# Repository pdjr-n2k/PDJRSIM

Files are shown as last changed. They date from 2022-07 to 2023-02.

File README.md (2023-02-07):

# PDJRSIM - NMEA 2000 switch input module

This project provides a
[hardware design](./hardware/)
and associated
[firmware](./firmware)
for a 16-channel NMEA 2000 switch input module.

There is also a
[User Manual](./docs)
for a device constructed from these components.

**PDJRSIM** is a specialisation of
[NOP100](https://github.com/preeve9534/NOP100).

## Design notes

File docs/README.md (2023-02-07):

# PDJRSIM - NMEA 2000 switch input module

**PDJRSIM** is a 16-channel NMEA 2000 switch input module.

The module presents on the NMEA bus as a switch bank device with
Class Code 30 (Electrical Distribution) and Function Code 130 (Binary
Event Monitor) and reports its status through transmission of
PGN 127501 Binary Status Report messages.

The module is powered from the host NMEA bus and has an LEN of 0.5.

**PDJRSIM** is a specialisation of
[NOP100](https://github.com/preeve9534/NOP100).

## Switch inputs

**PDJRSIM** supports sixteen input channels each of which is
optically isolated and reverse polarity protected with reference to
a common ground.

A voltage of between 5VDC and 50VDC on an input channel is interpreted
as an ON condition for that channel.
When ON the nominal current draw per channel from the external source
is 8mA at 12VDC, 10mA at 24VDC.

## Status reporting

**PDJRSIM** uses PGN 127501 to report the switch bank status.

By default a status report is transmitted once every two seconds when
the module inputs are quiescent, or immediately a state change is
detected on an input channel.
The quiescent transmission interval can be configured by the user.

## Module configuration

See [Appendix I - Module configuration parameters](#appendix-i---module-configuration-parameters).

The module must be configured with a module instance number before use.

### Setting the module's instance number

1. Enter the value 0x01 on the ADDR/VALUE DIL switch.
2. Press and hold the PRG button for 1s and then release.
   The transmit LED will commence flashing.
3. Enter the module instance number you wish to use on the ADDR/VALUE
   DIL switch.
4. Press and release the PRG button.
   The transmit LED will stop flashing.

The module will immediately begin transmitting status report messages
on the new instance number.

Select your instance number with care: the number used must not be in
use by any other switch bank on the host NMEA bus and must be in the
range 0 through 252.

You can disable the module by setting its instance number to 0xff.

### Setting the module's quiescent transmission interval

In most cases the default quiescent transmission interval of two seconds
will not need to be altered.
The NMEA 2000 specification proposes two seconds as an appropriate
minimum transmission interval for PGN 127501 and it is sensible to
respect this constraint.

If you do wish to change the quiescent transmission rate, then:

1. Enter the value 0x02 on the ADDR/VALUE DIL switch.
2. Press and hold the PRG button for 1s and then release.
   The transmit LED will commence flashing.
3. Enter your required transmission interval in seconds on the
   ADDR/VALUE DIL switch.
4. Press and release the PRG button.
   The transmit LED will stop flashing.

The module will immediately begin transmitting status report messages
at the new transmission rate.

## Connecting switch inputs

1. Connect a reference switch input ground to J1[1].

2. Connect up to a maximum of eight switch inputs to J1[2..9].
   Each input must supply an ON voltage in the range 5VDC through 50VDC
   relative to J1[1].
   Each input must be able to source around 10mA necessary to drive the
   opto-isolation input circuitry.

## Appendix I - Module configuration parameters

| Address | Name | Default value | Description |
| :---: | :--- | :---: | :--- |
| 0x00 | CAN SOURCE ADDRESS | 0x22 | RESERVED |
| 0x01 | MODULE INSTANCE NUMBER | 0xFF | Module instance number in the range 0 through 252. |
| 0x02 | PGN 127501 TRANSMISSION PERIOD | 0x02 | Quiescent transmission interval in seconds. |
| 0x03 | PGN 127501 TRANSMISSION OFFSET | 0x00 | Quiescent transmission offset in s/100. |

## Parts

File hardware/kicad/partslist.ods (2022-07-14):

 |  |  | Quantity | Supplier | Order No | Qtty in pack | Order Qtty | Unit cost | Item Cost
> C1, C2 | 560pF | D5.0, P2.50 | 2 | Farnell | 1835017 | 1 | 2 | 0.09 | 0.17
> C3, C4 | 100nF | D5.0, P2.50 | 2 | Farnell | 1457568 | 1 | 2 | 1.17 | 2.34
> D1-D4, D8, D9 | 1N4007 | DO-35 SOD27 P2.54 | 6 | Farnell | 2889101 | 5 | 2 | 0.23 | 0.45
> D5-D7 | PWR/TX | LED D3.0, P2.54 | 3 | Farnell | 1735246 | 5 | 1 | 0.31 | 0.31
F1 | 100mA | Littelfuse 395, P5.08 | 1 | Farnell | 2786454 | 1 | 1 | 3.69 | 3.69
F2 | 1A | Littelfuse 395, P5.08 | 1 | Farnell | 2786457 | 1 | 1 | 0.82 | 0.82
J1 | NPN SENSOR | Phoenix MPT 1x03 P2.54 | 1 | Farnell | 3041360 | 1 | 1 | 1.94 | 1.94
J2 | Screw_Terminal_01x05 | Phoenix MPT 1x05 P2.54 | 1 | Farnell | 2776439 | 1 | 1 | 3.20 | 3.20
J3 | M12-5PIN | Phoenix MPT 1x04 P2.54 | 1 | Farnell | 3041414 | 1 | 1 | 1.05 | 1.05
J4 | RELAYS | Phoenix MPT 1x06 P2.54 | 1 | Farnell | 3041426 | 1 | 1 | 3.70 | 3.70
> K1, K2 | Form C Relay | RS_RELAY_476-757 | 2 | RS | 476-757 | 1 | 2 | 2.29 | 4.58
> Q1, Q2 | 2N2219 | TO-39-3 | 2 | Farnell | 1611599 | 1 | 2 | 2.65 | 5.30
> R1-R4 | 1K4, 1W | DIN0207 L6.3 D2.5 P2.54 | 4 | Farnell | 6534478 | 10 | 1 | 0.40 | 0.40
> R5,R6,R8,R13 | 4K7, 125mW | DIN0204 L3.6 D1.6 P2.54 | 4 | Farnell | 9343253 | 5 | 1 | 0.03 | 0.03
> R7,R9,R10 | 200R, 125mW | DIN0204 L3.6 D1.6 P5.08 | 3 | Farnell | 9342770 | 5 | 1 | 0.03 | 0.03
> R11, R12 | 100R | DIN0204 L3.6 D1.6 P5.08 | 2 | Farnell | 9342397 | 5 | 1 | 0.03 | 0.03
SW1 | INSTANCE | DIP SPSTx08 Slide W7.62 P2.54 LowProfile | 1 | Farnell | 2452332 | 1 | 1 | 0.85 | 0.85
U1 | CNY74-4H | DIP-16 W7.62 | 1 | Farnell | 1045432 | 1 | 1 | 1.70 | 1.70
U2 | Teensy_3.2 | Teensy 32 LC | 1 | Pimoroni | TEENSY3.2 | 1 | 1 | 18.00 | 18.00
U3 | TEC2-2411WI | DCDC TRACO THT | 1 | Farnell | 2854919 | 1 | 1 | 8.07 | 8.07
U4 | MCP2551-I-P | DIP-8 W7.62 | 1 | Farnell | 1292240 | 1 | 1 | 0.90 | 0.90
E1 | Enclosure | RS 80x80 ABS | 1 | RS | 919-0357 | 1 | 1 | 2.63 | 2.63
 |  |  |  |  |  |  |  | TOTAL | 60.19

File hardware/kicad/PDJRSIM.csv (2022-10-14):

Component Count: | 100
Ref | Qnty | Value | Cmp name | Footprint | Description | Vendor
C1, C2, C3, C4, | 4 | 100nF | CP_Small | Capacitor_THT:CP_Radial_D5.0mm_P2.00mm | Polarized capacitor, small symbol
C5, C6, C7, C8, C9, C10, C11, C12, | 8 | 100nF | CP_Small | Capacitor_SMD:CP_Elec_4x4.5 | Polarized capacitor, small symbol
D1, D2, D3, D4, D5, D6, D7, D8, D9, | 9 | LED | LED | LED_THT:LED_D1.8mm_W3.3mm_H2.4mm | Light emitting diode
D10, D11, D12, D13, D14, D15, D16, D17, | 8 | IN4148 | DIODE | Diode_THT:D_A-405_P2.54mm_Vertical_AnodeUp | Diode, anode on pin 1, for simulation only!
F1, | 1 | 1A | Polyfuse | Fuse:Fuse_Littelfuse_395Series | Resettable fuse, polymeric positive temperature coefficient
J1, | 1 | Screw_Terminal_01x09 | Screw_Terminal_01x09 | PDJR-connectors:RS-PLUG-TERMINAL-HORIZ-9-PIN | Generic screw terminal, single row, 01x09, script generated (kicad-library-utils/schlib/autogen/connector/)
J2, | 1 | CAN | Screw_Terminal_01x05 | Connector_PinHeader_2.54mm:PinHeader_1x05_P2.54mm_Vertical | Generic screw terminal, single row, 01x05, script generated (kicad-library-utils/schlib/autogen/connector/)
Q1, Q3, Q5, Q7, Q9, Q11, Q13, Q15, | 8 | BC547 | BC547 | Package_TO_SOT_THT:TO-92_Inline | 0.1A Ic, 45V Vce, Small Signal NPN Transistor, TO-92
Q2, Q4, Q6, Q8, Q10, Q12, Q14, Q16, | 8 | BC337 | BC337 | Package_TO_SOT_THT:TO-92_Inline | 0.8A Ic, 45V Vce, NPN Transistor, TO-92
R1, | 1 | 4K7 0.125W | R | Resistor_THT:R_Axial_DIN0207_L6.3mm_D2.5mm_P2.54mm_Vertical | Resistor
R2, | 1 | 120R 0.5W | R | Resistor_THT:R_Axial_DIN0207_L6.3mm_D2.5mm_P7.62mm_Horizontal | Resistor
R3, | 1 | 4K7 | R | Resistor_THT:R_Axial_DIN0207_L6.3mm_D2.5mm_P2.54mm_Vertical | Resistor
R4, R7, R10, R13, R16, R19, R22, R25, | 8 | 10K 0.5W | R | Resistor_THT:R_Axial_DIN0207_L6.3mm_D2.5mm_P2.54mm_Vertical | Resistor
R5, R8, R11, R14, R17, R20, R23, R26, | 8 | 100R 0.25W | R | Resistor_THT:R_Axial_DIN0207_L6.3mm_D2.5mm_P2.54mm_Vertical | Resistor
R6, R9, R12, R15, R18, R21, R24, R27, | 8 | 4K7 0.125W | R | Resistor_SMD:R_0603_1608Metric_Pad0.98x0.95mm_HandSolder | Resistor
RN1, | 1 | R_Network08 | R_Network08 | Resistor_THT:R_Array_SIP9 | 8 resistor network, star topology, bussed resistors, small symbol
SW1, | 1 | PRG | SW_Push | PDJR-connectors:PCB_PUSH_BUTTON | Push button switch, generic, two pins
SW2, | 1 | INSTANCE | SW_DIP_x08 | Package_DIP:DIP-16_W7.62mm | 8x DIP Switch, Single Pole Single Throw (SPST) switch, small symbol
SW3, | 1 | BUS | SW_DIP_x02 | Package_DIP:DIP-4_W7.62mm_LongPads | 2x DIP Switch, Single Pole Single Throw (SPST) switch, small symbol
U1, | 1 | MCP2551-I-P | MCP2551-I-P | Package_DIP:DIP-8_W7.62mm | High-Speed CAN Transceiver, 1Mbps, 5V supply, DIP-8
U2, | 1 | TMR_2411 | TMR_2411-pdjr | PDJR-connectors:TMR_2411
U3, U7, U9, U11, U13, U15, U17, U19, U21, | 9 | MAX6816 | MAX6816 | Package_TO_SOT_SMD:SOT-143 | Single Switch Debouncer, SOT-143
U4, | 1 | 74HC595 | 74HC595 | Package_DIP:DIP-16_W7.62mm_Socket_LongPads | 8-bit serial in/out Shift Register 3-State Outputs
U5, | 1 | Teensy_3.2 | Teensy_3.2-pdjr | Package_DIP:DIP-28_W15.24mm_LongPads
U6, U8, U10, U12, U14, U16, U18, U20, | 8 | SFH617A-1 | SFH617A-1 | Package_DIP:DIP-4_W7.62mm | Optocoupler, Phototransistor Output, 5300 VRMS, VCEO 70V, CTR% 40-80, -55 to +110 degree Celcius, UL, BSI, FIMKO, cUL, THT PDIP-4

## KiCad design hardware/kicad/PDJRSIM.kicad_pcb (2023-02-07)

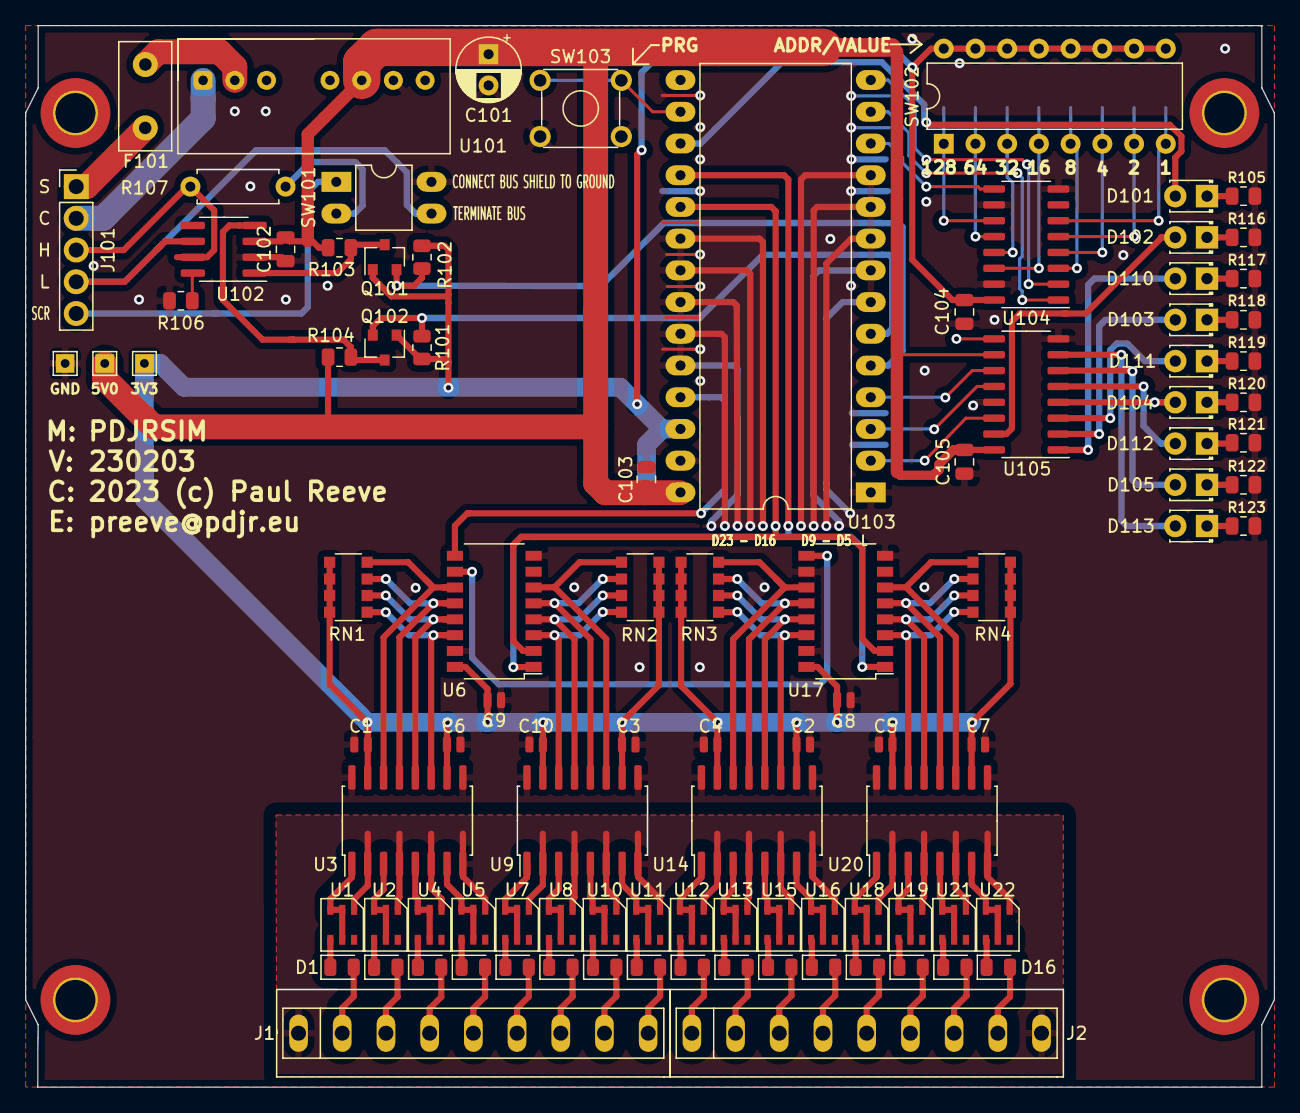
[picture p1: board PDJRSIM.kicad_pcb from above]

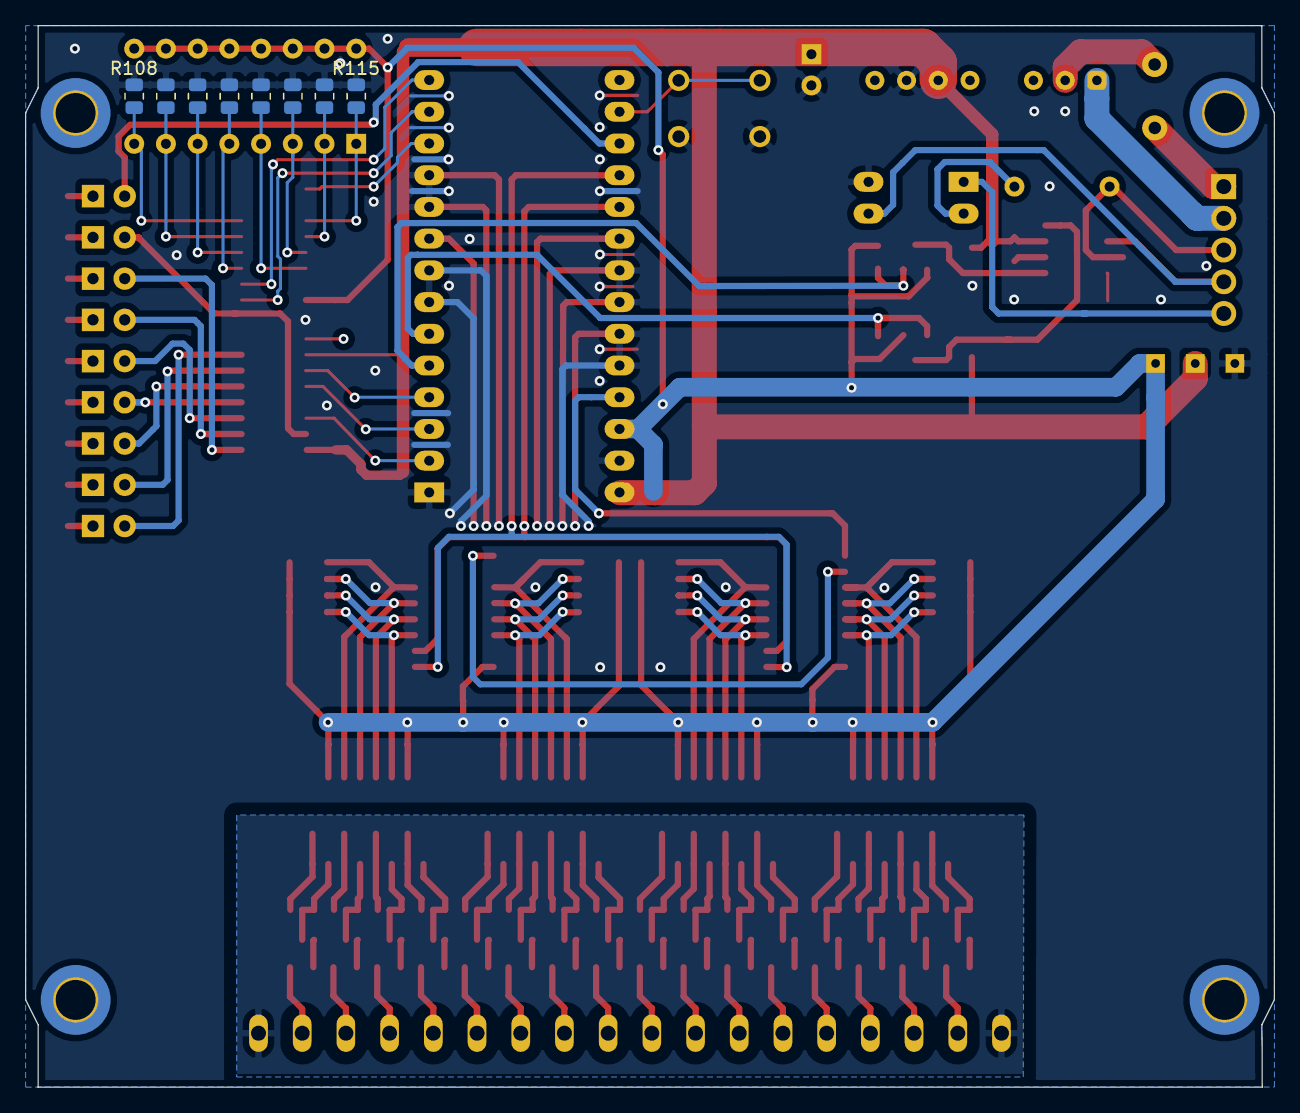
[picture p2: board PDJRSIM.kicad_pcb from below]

Board: 2 copper layers, 100.0 x 85.0 mm, 105 parts (8 on the bottom side), 117 nets.

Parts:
C1, C2, C3, C4, C5, C6, C7, C8, C9, C10: 100nF; C_0504_1310Metric
C101: 100nF; CP_Radial_D5.0mm_P2.50mm
C102, C103, C104, C105: 100nF; C_0805_2012Metric
D1, D2, D3, D4, D5, D6, D7, D8, D9, D10, D11, D12, D13, D14, D15, D16: D_Small; D_0805_2012Metric
D101, D102, D103, D104, D105, D110, D111, D112, D113: LED; LED_D1.8mm_W3.3mm_H2.4mm
F101: 1A; Fuse_Littelfuse_395Series
J1, J2: Screw_Terminal_01x09; 897-1357-9-PIN-3-5-CONN
J101: CAN; PinHeader_1x05_P2.54mm_Vertical
Q101, Q102: BSS138; SOT-23
R101, R102, R103, R104: 10K 0.125W; R_0805_2012Metric
R105, R116, R117, R118, R119, R120, R121, R122, R123: 560R; R_0805_2012Metric
R106, R108, R109, R110, R111, R112, R113, R114, R115: 4K7 0.125W; R_0805_2012Metric
R107: 120R 0.5W; R_Axial_DIN0207_L6.3mm_D2.5mm_P7.62mm_Horizontal
RN1, RN2, RN3, RN4: 4K; R_Array_Convex_4x1206
SW101: BUS; DIP-4_W7.62mm_LongPads
SW102: ADDR/VALUE; DIP-16_W7.62mm
SW103: PRG; SW_TH_Tactile_Omron_B3F-10xx
TEST 5V0, TEST 5V0#2: TestPoint_THTPad_1.5x1.5mm_Drill0.7mm
U1, U2, U4, U5, U7, U8, U10, U11, U12, U13, U15, U16, U18, U19, U21, U22: BCR401
U3, U9, U14, U20: ASCL-6400; SO-16_5.3x10.2mm_P1.27mm
U6, U17: 74LS165; SOP-16_4.4x10.4mm_P1.27mm
U101: TMR-2-2411; TMR_2411
U102: MCP2551-I-P; SOIC-8_3.9x4.9mm_P1.27mm
U103: Teensy_4.0; DIP-28_W15.24mm_LongPads
U104: 74HC165; SO-16_3.9x9.9mm_P1.27mm
U105: 74HCT595; SO-16_3.9x9.9mm_P1.27mm

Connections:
+3V3: C1.1, C2.1, C3.1, C4.1, C5.1, C6.1, C7.1, C8.1, C9.1, C10.1, C104.1, Q101.1, Q102.1, R101.2, R102.2, RN1.5, RN1.6, RN1.7, RN1.8, RN2.5, RN2.6, RN2.7, RN2.8, RN3.5, RN3.6, RN3.7, RN3.8, RN4.5, RN4.6, RN4.7, RN4.8, SW102.9, SW102.10, SW102.11, SW102.12, SW102.13, SW102.14, SW102.15, SW102.16, TEST 5V0.1, U3.10, U3.15, U6.16, U9.10, U9.15, U14.10, U14.15, U17.16, U20.10, U20.15, U103.26, U104.16
+5V: C101.1, C102.1, C103.1, C105.1, R103.2, R104.2, TEST 5V0#2.1, U101.6, U102.3, U103.28, U105.10, U105.16
/CAN_RX: Q102.2, R101.1, U103.6
/CAN_TX: Q101.2, R102.1, U103.5
/D16: U6.1, U17.1, U103.18
/D17: U6.2, U17.2, U103.19
/D23: U6.9, U103.25
/PISO_CP: U103.14, U104.2
/PISO_PL: U103.13, U104.1
/PISO_Q7: U103.12, U104.9
/PRG: SW103.1, SW103.2, U103.16
/SIPO_CLOCK: U103.4, U105.11
/SIPO_DATA: U103.2, U105.14
/SIPO_LATCH: U103.3, U105.12
GND: C1.2, C2.2, C3.2, C4.2, C5.2, C6.2, C7.2, C8.2, C9.2, C10.2, C101.2, C102.2, C103.2, C104.2, C105.2, R105.2, R106.1, R108.2, R109.2, R110.2, R111.2, R112.2, R113.2, R114.2, R115.2, R116.2, R117.2, R118.2, R119.2, R120.2, R121.2, R122.2, R123.2, SW101.4, SW103.3, SW103.4, U3.9, U3.16, U6.8, U6.15, U9.9, U9.16, U14.9, U14.16, U17.8, U17.10, U17.15, U20.9, U20.16, U101.7, U102.2, U103.1, U103.7, U103.8, U103.9, U103.10, U103.11, U103.20, U103.21, U103.22, U103.23, U103.24, U103.27, U104.8, U104.10, U104.15, U105.8, U105.13
unnamed: D1.1, U1.4
unnamed: D1.2, J1.2
unnamed: D2.1, U2.4
unnamed: D2.2, J1.3
unnamed: D3.1, U4.4
unnamed: D3.2, J1.4
unnamed: D4.1, U5.4
unnamed: D4.2, J1.5
unnamed: D5.1, U7.4
unnamed: D5.2, J1.6
unnamed: D6.1, U8.4
unnamed: D6.2, J1.7
unnamed: D7.1, U10.4
unnamed: D7.2, J1.8
unnamed: D8.1, U11.4
unnamed: D8.2, J1.9
unnamed: D9.1, U12.4
unnamed: D9.2, J2.1
unnamed: D10.1, U13.4
unnamed: D10.2, J2.2
unnamed: D11.1, U15.4
unnamed: D11.2, J2.3
unnamed: D12.1, U16.4
unnamed: D12.2, J2.4
unnamed: D13.1, U18.4
unnamed: D13.2, J2.5
unnamed: D14.1, U19.4
unnamed: D14.2, J2.6
unnamed: D15.1, U21.4
unnamed: D15.2, J2.7
unnamed: D16.1, U22.4
unnamed: D16.2, J2.8
unnamed: D101.1, R105.1
unnamed: D101.2, U103.17
unnamed: D102.1, R116.1
unnamed: D102.2, U105.15
unnamed: D103.1, R118.1
unnamed: D103.2, U105.2
unnamed: D104.1, R120.1
unnamed: D104.2, U105.4
unnamed: D105.1, R122.1
unnamed: D105.2, U105.6
unnamed: D110.1, R117.1
unnamed: D110.2, U105.1
unnamed: D111.1, R119.1
unnamed: D111.2, U105.3
unnamed: D112.1, R121.1
unnamed: D112.2, U105.5
unnamed: D113.1, R123.1
unnamed: D113.2, U105.7
unnamed: F101.1, J101.1
unnamed: F101.2, U101.2
unnamed: J1.1, J2.9, U1.1, U2.1, U3.2, U3.4, U3.6, U3.8, U4.1, U5.1, U7.1, U8.1, U9.2, U9.4, U9.6, U9.8, U10.1, U11.1, U12.1, U13.1, U14.2, U14.4, U14.6, U14.8, U15.1, U16.1, U18.1, U19.1, U20.2, U20.4, U20.6, U20.8, U21.1, U22.1
unnamed: J101.2, U101.1
unnamed: J101.3, R107.1, U102.7
unnamed: J101.4, SW101.3, U102.6
unnamed: J101.5, SW101.1
unnamed: Q101.3, R103.1, U102.1
unnamed: Q102.3, R104.1, U102.4
unnamed: R106.2, U102.8
unnamed: R107.2, SW101.2
unnamed: R108.1, SW102.8, U104.6
unnamed: R109.1, SW102.7, U104.5
unnamed: R110.1, SW102.6, U104.4
unnamed: R111.1, SW102.5, U104.3
unnamed: R112.1, SW102.4, U104.14
unnamed: R113.1, SW102.3, U104.13
unnamed: R114.1, SW102.2, U104.12
unnamed: R115.1, SW102.1, U104.11
unnamed: RN1.1, U3.11, U6.14
unnamed: RN1.2, U3.12, U6.13
unnamed: RN1.3, U3.13, U6.12
unnamed: RN1.4, U3.14, U6.11
unnamed: RN2.1, U6.6, U9.11
unnamed: RN2.2, U6.5, U9.12
unnamed: RN2.3, U6.4, U9.13
unnamed: RN2.4, U6.3, U9.14
unnamed: RN3.1, U14.11, U17.14
unnamed: RN3.2, U14.12, U17.13
unnamed: RN3.3, U14.13, U17.12
unnamed: RN3.4, U14.14, U17.11
unnamed: RN4.1, U17.6, U20.11
unnamed: RN4.2, U17.5, U20.12
unnamed: RN4.3, U17.4, U20.13
unnamed: RN4.4, U17.3, U20.14
unnamed: U1.2, U1.3, U1.5, U3.1
unnamed: U2.2, U2.3, U2.5, U3.3
unnamed: U3.5, U4.2, U4.3, U4.5
unnamed: U3.7, U5.2, U5.3, U5.5
unnamed: U7.2, U7.3, U7.5, U9.1
unnamed: U8.2, U8.3, U8.5, U9.3
unnamed: U9.5, U10.2, U10.3, U10.5
unnamed: U9.7, U11.2, U11.3, U11.5
unnamed: U12.2, U12.3, U12.5, U14.1
unnamed: U13.2, U13.3, U13.5, U14.3
unnamed: U14.5, U15.2, U15.3, U15.5
unnamed: U14.7, U16.2, U16.3, U16.5
unnamed: U6.10, U17.9
unnamed: U18.2, U18.3, U18.5, U20.1
unnamed: U19.2, U19.3, U19.5, U20.3
unnamed: U20.5, U21.2, U21.3, U21.5
unnamed: U20.7, U22.2, U22.3, U22.5

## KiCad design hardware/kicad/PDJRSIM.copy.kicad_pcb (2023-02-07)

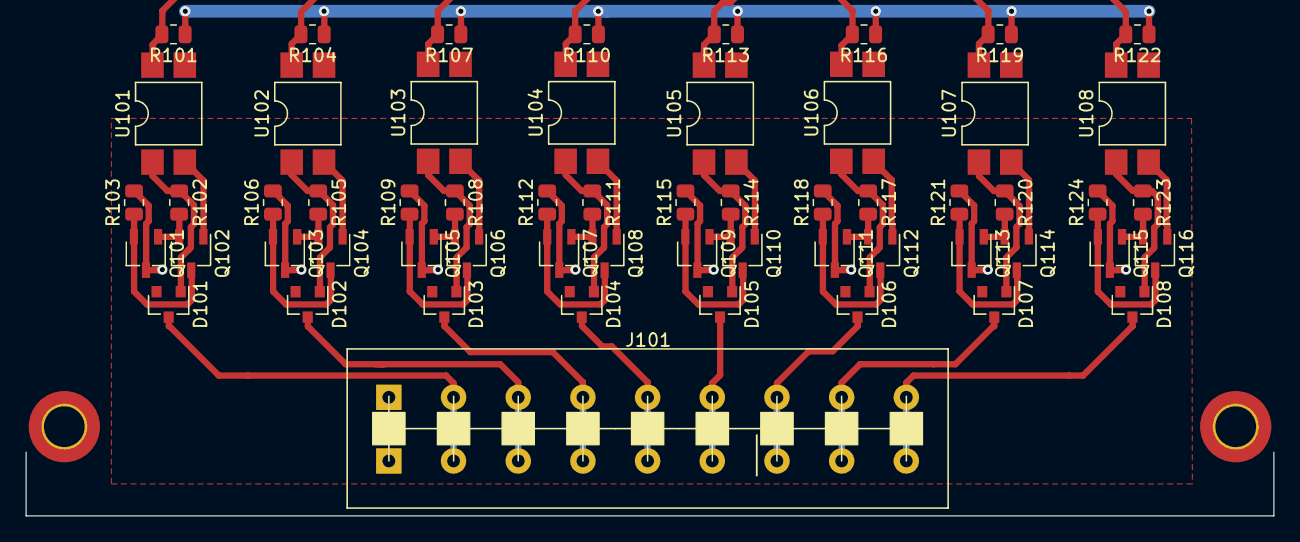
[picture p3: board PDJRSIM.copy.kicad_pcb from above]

Board: 2 copper layers, 57 parts (0 on the bottom side), 51 nets.

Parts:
D101, D102, D103, D104, D105, D106, D107, D108: IN4007; D_SOT-23_ANK
J101: Screw_Terminal_01x09; CAMDEN_BOSS_CSTBV2-9_TERMINAL
Q101, Q103, Q105, Q107, Q109, Q111, Q113, Q115: BC547; TSOT-23
Q102, Q104, Q106, Q108, Q110, Q112, Q114, Q116: BC337-40; TSOT-23
R101, R104, R107, R110, R113, R116, R119, R122: 4K7 0.125W; R_0805_2012Metric
R102, R105, R108, R111, R114, R117, R120, R123: 10K 0.5W; R_0805_2012Metric
R103, R106, R109, R112, R115, R118, R121, R124: 100R 0.25W; R_0805_2012Metric
U101, U102, U103, U104, U105, U106, U107, U108: SFH617A-1; SMDIP-4_W7.62mm

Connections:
+3V3: R101.1, R104.1, R107.1, R110.1, R113.1, R116.1, R119.1, R122.1
/D16: R122.2, U108.4
/D17: R119.2, U107.4
/D18: R116.2, U106.4
/D19: R113.2, U105.4
/D20: R110.2, U104.4
/D21: R107.2, U103.4
/D22: R104.2, U102.4
/D23: R101.2, U101.4
/SPST_GND: J101.1, Q101.3, Q103.3, Q105.3, Q107.3, Q109.3, Q111.3, Q113.3, Q115.3, R103.2, R106.2, R109.2, R112.2, R115.2, R118.2, R121.2, R124.2
GND: U101.3, U102.3, U103.3, U104.3, U105.3, U106.3, U107.3, U108.3
unnamed: D101.1, J101.2
unnamed: D101.2, R102.1, U101.1
unnamed: D102.1, J101.3
unnamed: D102.2, R105.1, U102.1
unnamed: D103.1, J101.4
unnamed: D103.2, R108.1, U103.1
unnamed: D104.1, J101.5
unnamed: D104.2, R111.1, U104.1
unnamed: D105.1, J101.6
unnamed: D105.2, R114.1, U105.1
unnamed: D106.1, J101.7
unnamed: D106.2, R117.1, U106.1
unnamed: D107.1, J101.8
unnamed: D107.2, R120.1, U107.1
unnamed: D108.1, J101.9
unnamed: D108.2, R123.1, U108.1
unnamed: Q101.1, Q102.2, R102.2
unnamed: Q101.2, Q102.3, R103.1
unnamed: Q102.1, U101.2
unnamed: Q103.1, Q104.2, R105.2
unnamed: Q103.2, Q104.3, R106.1
unnamed: Q104.1, U102.2
unnamed: Q105.1, Q106.2, R108.2
unnamed: Q105.2, Q106.3, R109.1
unnamed: Q106.1, U103.2
unnamed: Q107.1, Q108.2, R111.2
unnamed: Q107.2, Q108.3, R112.1
unnamed: Q108.1, U104.2
unnamed: Q109.1, Q110.2, R114.2
unnamed: Q109.2, Q110.3, R115.1
unnamed: Q110.1, U105.2
unnamed: Q111.1, Q112.2, R117.2
unnamed: Q111.2, Q112.3, R118.1
unnamed: Q112.1, U106.2
unnamed: Q113.1, Q114.2, R120.2
unnamed: Q113.2, Q114.3, R121.1
unnamed: Q114.1, U107.2
unnamed: Q115.1, Q116.2, R123.2
unnamed: Q115.2, Q116.3, R124.1
unnamed: Q116.1, U108.2

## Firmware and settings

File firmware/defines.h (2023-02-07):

/**
 * @file defines.h
 * @author Paul Reeve (preeve@pdjr.eu)
 * @brief Defines for PDJRSIM.
 * @version 0.1
 * @date 2023-01-16
 * @copyright Copyright (c) 2023
 */

/**********************************************************************
 * @brief GPIO pin definition aliases.
 */
#define GPIO_PISO_SWITCH_DATA GPIO_D23
#define GPIO_PISO_SWITCH_LATCH GPIO_D16
#define GPIO_PISO_SWITCH_CLOCK GPIO_D17

/**********************************************************************
 * @brief NMEA2000 device information overrides.
 */
#define DEVICE_CLASS 30                 // Electrical Distribution
#define DEVICE_FUNCTION 130             // Binary Event Monitor
#define DEVICE_UNIQUE_NUMBER 108        // Bump me?

/**********************************************************************
 * @brief NMEA2000 product information overrides.
 */
#define PRODUCT_CODE 002
#define PRODUCT_FIRMWARE_VERSION "230203"
#define PRODUCT_LEN 1
#define PRODUCT_SERIAL_CODE "002-108"   // PRODUCT_CODE + DEVICE_UNIQUE_NUMBER
#define PRODUCT_TYPE "PDJRSIM"           // The product name?
#define PRODUCT_VERSION "230203 (Feb 2022)"

/**********************************************************************
 * @brief NMEA2000 transmit and receive PGN overrides.
 */
#define NMEA_TRANSMITTED_PGNS { 127501L, 0 }

/**********************************************************************
 * @brief ModuleConfiguration library stuff.
 */
#define MODULE_CONFIGURATION_SIZE 4                               // Total configuration size in bytes

#define MODULE_CONFIGURATION_INSTANCE_INDEX 1                     // Index of module instance number
#define MODULE_CONFIGURATION_PGN127501_TRANSMIT_PERIOD_INDEX 2    // Index of PGN 127501 transmit period in seconds
#define MODULE_CONFIGURATION_PGN127501_TRANSMIT_OFFSET_INDEX 3    // Index of PGN 127501 transmit offset in 10s of milli-seconds

#define MODULE_CONFIGURATION_INSTANCE_DEFAULT 0xff                // Disabled
#define MODULE_CONFIGURATION_TRANSMIT_PERIOD_DEFAULT 0x02         // Every two seconds
#define MODULE_CONFIGURATION_TRANSMIT_OFFSET_DEFAULT 0x00         // Zero times 10 milliseconds

#define MODULE_CONFIGURATION_DEFAULT { \
  MODULE_CONFIGURATION_CAN_SOURCE_DEFAULT, \
  MODULE_CONFIGURATION_INSTANCE_DEFAULT, \
  MODULE_CONFIGURATION_TRANSMIT_PERIOD_DEFAULT, \
  MODULE_CONFIGURATION_TRANSMIT_OFFSET_DEFAULT \
}

/**********************************************************************
 * @brief NOP100 function overrides.
 */
#define CONFIGURATION_VALIDATOR
#define ON_N2K_OPEN

/**********************************************************************
 * @brief Number of supported switch inputs.
 */
#define NUMBER_OF_SWITCH_INPUTS 16

/**********************************************************************
 * @brief number of milliseconds between checks on switch input channel
 * states.
 */
#define SWITCH_PROCESS_INTERVAL 100

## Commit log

2022-07-14 First initialisation
    Raw copy of TMP108
    [Infineon_PG-LLGA-5-1.FCStd, L_Coilcraft_LPS5030.FCStd, L_Wuerth_WE-TPC-3816.FCStd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]
2022-08-01 First circuit design
    [SIM108.csv, SIM108.kicad_pcb, SIM108.sch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]
2022-08-03 Revised opto isolation
    [SIM108.kicad_pcb, SIM108.sch]
2022-08-05 Constant current inputs
    [SIM108.kicad_pcb, SIM108.sch]
2022-08-08 Draft user guide
    [SIM108.kicad_pcb, SIM108.sch]
2022-08-17 Beginning to code...
    [SIM108.kicad_pcb, multiplexed_led_output.sch, opto_isolated_input.sch]
2022-08-22 README update
    [SIM108.kicad_pcb]
2022-08-26 Trivial updates
    [SIM108.kicad_pcb]
2022-09-30 New board size
    [SIM108.kicad_pcb, SIM108.sch, opto_isolated_input.sch]
2022-10-01 PCB tweaks
    [SIM108.kicad_pcb]
2022-10-01 PCB tweak
    [SIM108.kicad_pcb, SIM108.sch]
2022-10-10 PCB layout
    [SIM108.kicad_pcb]
2022-10-10 Update PCB
    [SIM108.kicad_pcb]
2022-10-13 Add transmit LED
    [SIM108.kicad_pcb, SIM108.sch, opto_isolated_input.sch]
2022-10-13 Transmit LED
    [SIM108.kicad_pcb]
2022-10-14 Change PCB conn
    [SIM108.kicad_pcb, SIM108.sch, opto_isolated_input.sch]
2022-10-14 Update connector
    [SIM108.csv, SIM108.sch]
2022-10-15 Update PCB hole sizes
    [SIM108.kicad_pcb]
2022-10-15 Centre switch connector
    [SIM108.kicad_pcb]
2022-10-15 Add mount holes
    [SIM108.kicad_pcb, SIM108.sch, opto_isolated_input.sch]
2022-10-15 Change to Camden Boss connector
    [SIM108.kicad_pcb, SIM108.sch]
2022-10-25 PCB reroute
    [SIM108.kicad_pcb]
2022-10-29 Change relay terminal
    [SIM108.kicad_pcb]
2022-11-05 Silk text
    [SIM108.kicad_pcb]
2022-11-05 Add silk text
    [SIM108.kicad_pcb]
2022-11-07 Pcb resize
    [SIM108.kicad_pcb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]
2022-11-29 Add jumper alternative to SW2
    [SIM108.kicad_pcb, SIM108.sch]
2022-11-30 Swap passive SMD for TH
    [SIM108-B_Cu.gbl, SIM108-B_Mask.gbs, SIM108-Edge_Cuts.gm1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]
2022-11-30 PCB silk update
    [SIM108.kicad_pcb]
2022-12-01 Revise for 3.3V
    [SIM108.kicad_pcb, SIM108.sch]
2022-12-01 Migrate to Teens 4.0
    3.3V inputs
    [SIM108.kicad_pcb, SIM108.sch, opto_isolated_input.sch]
2022-12-03 Move to SMD
    [SIM108.kicad_pcb, SIM108.sch, opto_isolated_input.sch]
2022-12-04 SIlk edit
    [SIM108.kicad_pcb, SIM108.sch]
2022-12-04 Switch to software debounce
2022-12-05 Add test points
    [SIM108.kicad_pcb, SIM108.sch, opto_isolated_input.sch]
2022-12-05 Test points
    [SIM108.kicad_pcb]
2022-12-06 Revise PCB
    [SIM108.kicad_pcb, opto_isolated_input.sch]
2022-12-06 Edit silk.
    [SIM108.kicad_pcb, opto_isolated_input.sch]
2022-12-06 Silk edit.
    [SIM108.kicad_pcb, SIM108.sch]
2022-12-19 Relay PCB
    [SIM108.kicad_pcb]
2022-12-27 Use new NOP100
    [SIM108.copy.kicad_pcb, SIM108.kicad_pcb, SIM108.sch]
2023-02-01 New PCB layout
    [SIM108.kicad_pcb, SIM108.sch]
2023-02-05 Gerber order
    [SIM108.kicad_pcb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]
2023-02-07 Fix a break
    [PDJRSIM.kicad_pcb, PDJRSIM.sch]
